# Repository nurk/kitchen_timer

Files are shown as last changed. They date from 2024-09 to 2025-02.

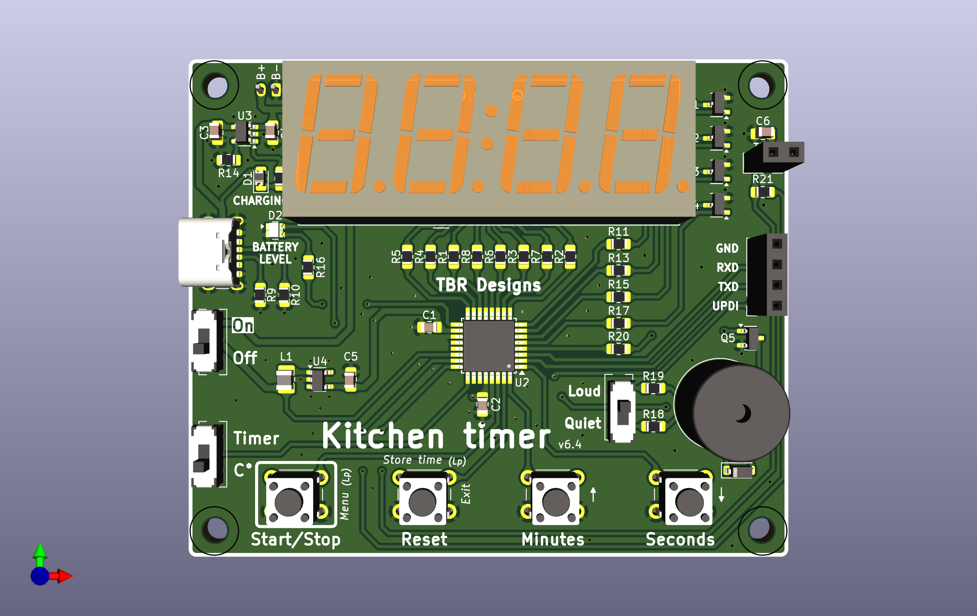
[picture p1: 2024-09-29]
hardware/kitchen_timer_6.4/3D.png

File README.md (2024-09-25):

### *Disclaimer*
*I am not a microcontroller developer nor am I a C-plusplus developer.  I am also definitively not a hardware designer.*

# Kitchen timer

A long time ago my lovely sister gave me a kitchen timer which would beep once when there are 10 minutes left and twice when there are 5 minutes left.  Unfortunately time got the better of the timer and it broke but I got hooked on those features.

I have been unable to find a replacement but after dabbling with some [circuits](https://github.com/nurk/8-bit-cpu) a bit I thought I might be able to make my own.

This repository contains the version(s) that I deem worthy of the internet.

You will find a software and hardware folder with each containing the respective versions.

The hardware folder contains a KiCad project where the symbols and footprints used have been added to a local library.  You will also find a pdf of the [schematic](https://github.com/nurk/kitchen_timer/blob/ce0c0dc44edd9d53a935f777b976885855d0056c/hardware/kitchen_timer_6.3/schematic.pdf), a screenshot of the [pcb](https://github.com/nurk/kitchen_timer/blob/ce0c0dc44edd9d53a935f777b976885855d0056c/hardware/kitchen_timer_6.3/pcb.png) and a screenshot of the [3D rendering](https://github.com/nurk/kitchen_timer/blob/ce0c0dc44edd9d53a935f777b976885855d0056c/hardware/kitchen_timer_6.3/3D.png).

The software folder contains an arduino ide project with the, well, software.

## User guide
I am not going to explain how to use a kitchen timer.  If the main function of the 4 buttons does not speak for themselves I did really bad.  I am only going to explain the extra features.

### Timer / C°
This switch toggles the display to show the timer and the measured temperature.

### Loud / Quiet
I bought cheap buzzers on amazon and they all seem a bit different.  Some are quiet and some are loud.  Because I was tired of changing the inline resistor for the buzzer I added a toggle to switch between two values.  One is louder, the other is quieter.

### Reset long press
Because you can fully turn off this device a way was needed to set the time for when you turn on the device.  The chance of you needing a timer of 0 minutes and 0 seconds is very slim.

After setting a time you can long press the **Reset** button until you hear a second beep and the set time will be stored.  When cycling the power the stored time will be loaded.

### Start/Stop long press
When you long press the **Start/Stop** button the letter `A` will appear and you will have entered the setup menu.  After releasing the **Start/Stop** button you will see `A5. 0`.  Clicking the **Start/Stop** button will cycle through the menu items:  
| Displayed | Meaning |
| :---: | :---: |
| `A5. 0` | 5 minute alarm  |
| `A10.0` | 10 minute alarm |
| `A15.0` | 15 minute alarm |
| `A20.0` | 20 minute alarm |
| `C 0.0` | Temperature offset<sup>*</sup> |

<sup>*</sup> This was added in version 6.4.  It is a `C` because I cannot make a `T` with a 7-segment display.

For the alarms, the value after the `.` is the number of beeps that will sound when there are 'x' minutes left.  You can use the **Minutes** button to increase the number of beeps and the **Seconds** button to decrease the number of beeps.

To exit the setup menu just click the **Reset** button.

## Miscellaneous
Some component sizes might seem big for some.  Especially resistors and capacitors of size 0805.  Keep in mind I am hand soldering this and I am becoming an old fart with bad eyesight.

The microcontroller is an ATmega4808 which has way more flash storage than is needed.  I still chose this one because it is what I have and I am not going to buy a new variant for each project I do.

The battery charge controller I chose only charges at 500mA.  So you will need a battery with at least this capacity (or you have to change the resistor on the programming pin).  I have a 2000mA battery connected and I takes a fair while to charge.

**This is not a cost effective way to get a kitchen timer.  If you need one you are better of going to the store and buying one.**

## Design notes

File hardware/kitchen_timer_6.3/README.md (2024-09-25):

The battery indicator does not work on this version.

I connected the battery voltage to PIN_PF0 but that pin cannot do `analogRead`.

Version 6.4 fixes this issue.

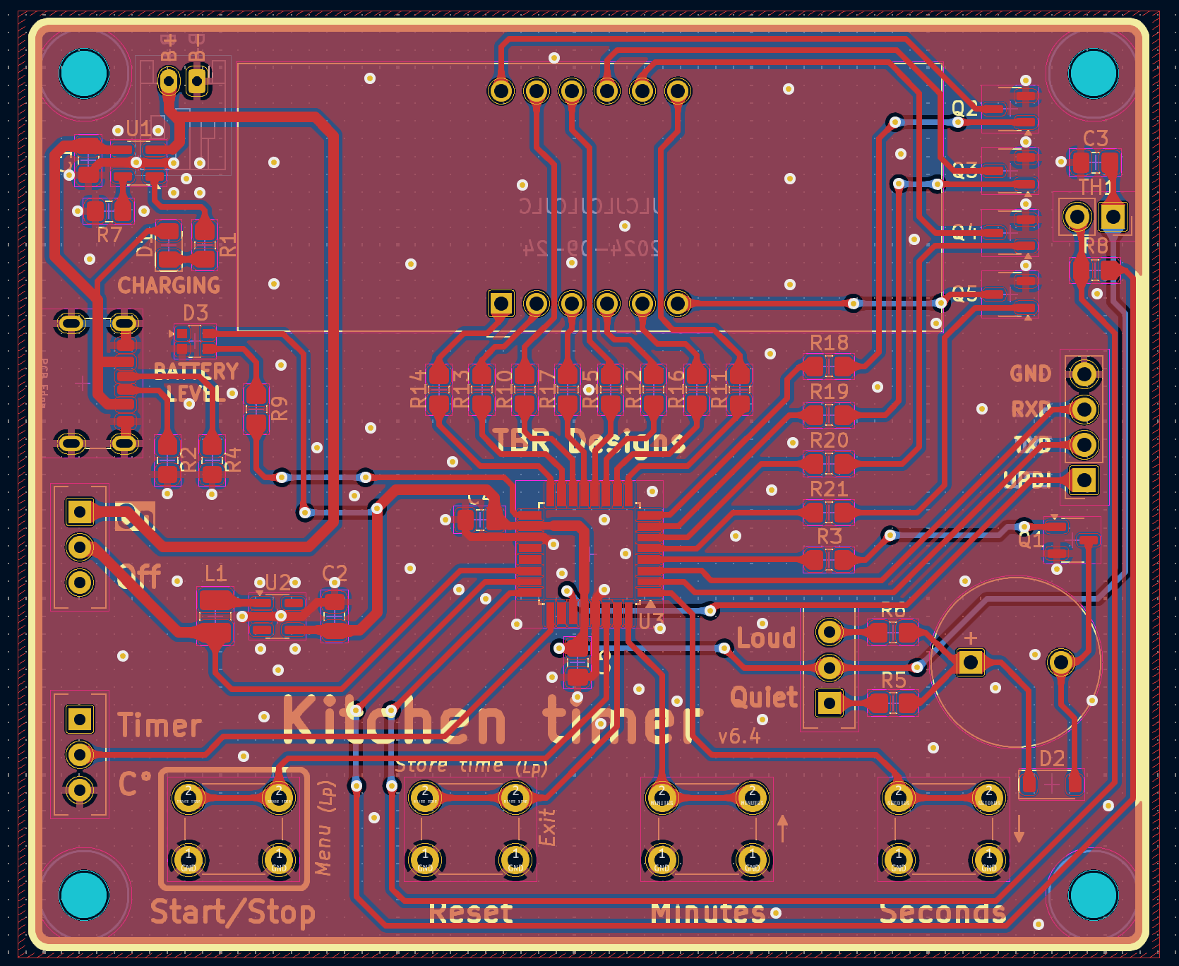
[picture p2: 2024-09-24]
hardware/kitchen_timer_6.4/pcb.png

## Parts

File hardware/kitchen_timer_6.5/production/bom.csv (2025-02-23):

Designator | Footprint | Quantity | Value | LCSC Part #
BZ1 | MagneticBuzzer_ProSignal_ABT-410-RC | 1 | Buzzer
C1, C2, C6 | 0805 | 3 | 100n
C3 | 0805 | 1 | 10u
C4, C5 | 0805 | 2 | 22u
D1 | 0805 | 1 | CHRG_LED
D2 | LED_WS2812B-2020_2.0x2.0mm | 1 | WS2812B-2020
D3 | D_SOD-123 | 1 | MBR0520
J1 | JST_PH_S2B-PH-K_1x02_P2.00mm_Horizontal | 1 | JST PH 2.0
J2 | USB_C_Receptacle_GCT_USB4125-xx-x-0190_6P_TopMnt_Horizontal | 1 | USB_C
J3 | PinSocket_1x04_P2.54mm_Vertical | 1 | BREAKOUT
L1 | 1008 | 1 | CVH252009-2R2M
Q1, Q2, Q3, Q4, Q5 | SOT-23-3 | 5 | MMBT2222A
R1, R2, R3, R4, R5, R6, R7, R8 | 0805 | 8 | 220R
R10, R9 | 0805 | 2 | 5k1 1%
R11, R12, R13, R15, R17, R20 | 0805 | 6 | 1k
R14 | 0805 | 1 | 2k 1%
R16 | 0805 | 1 | 300R
R18 | 0805 | 1 | 47R
R19 | 0805 | 1 | 5R
R21 | 0805 | 1 | 10k 1%
SW1 | SW_Slide_SPDT_MINI | 1 | ON/OFF
SW2 | SW_PUSH_6mm | 1 | SECONDS
SW3 | SW_PUSH_6mm | 1 | MINUTES
SW4 | SW_PUSH_6mm | 1 | RESET_TIME
SW5 | SW_Slide_SPDT_MINI | 1 | VOLUME
SW6 | SW_PUSH_6mm | 1 | START/STOP
SW7 | SW_Slide_SPDT_MINI | 1 | FUNCTION_SELECTOR
TH1 | PinSocket_1x02_P2.54mm_Vertical | 1 | NRBE104F3435B2F
U1 | CA56-12EWA | 1 | LTC-5723HR
U2 | TQFP-32_7x7mm_P0.8mm | 1 | ATmega4808-A
U3 | SOT-23-5 | 1 | DIO5518B
U4 | SOT-23-5 | 1 | TPS613222ADBV
U5 | SOT-23-5 | 1 | LM321

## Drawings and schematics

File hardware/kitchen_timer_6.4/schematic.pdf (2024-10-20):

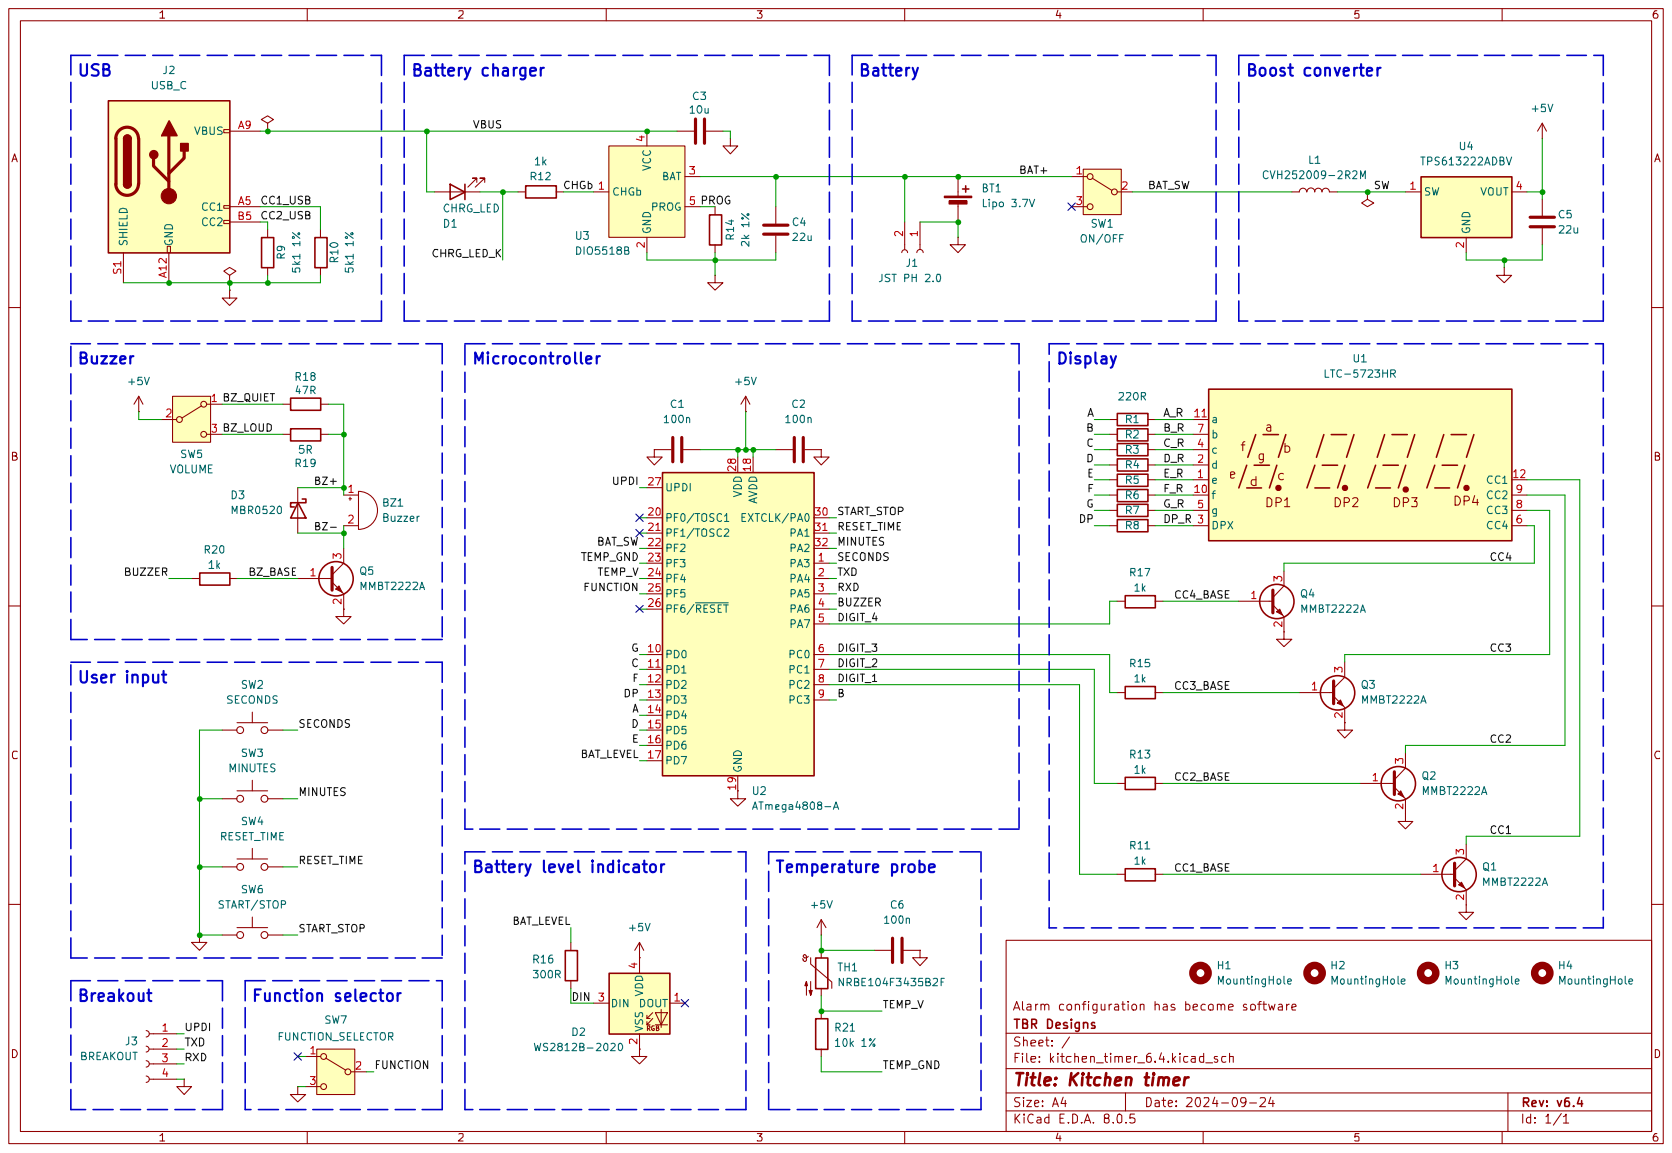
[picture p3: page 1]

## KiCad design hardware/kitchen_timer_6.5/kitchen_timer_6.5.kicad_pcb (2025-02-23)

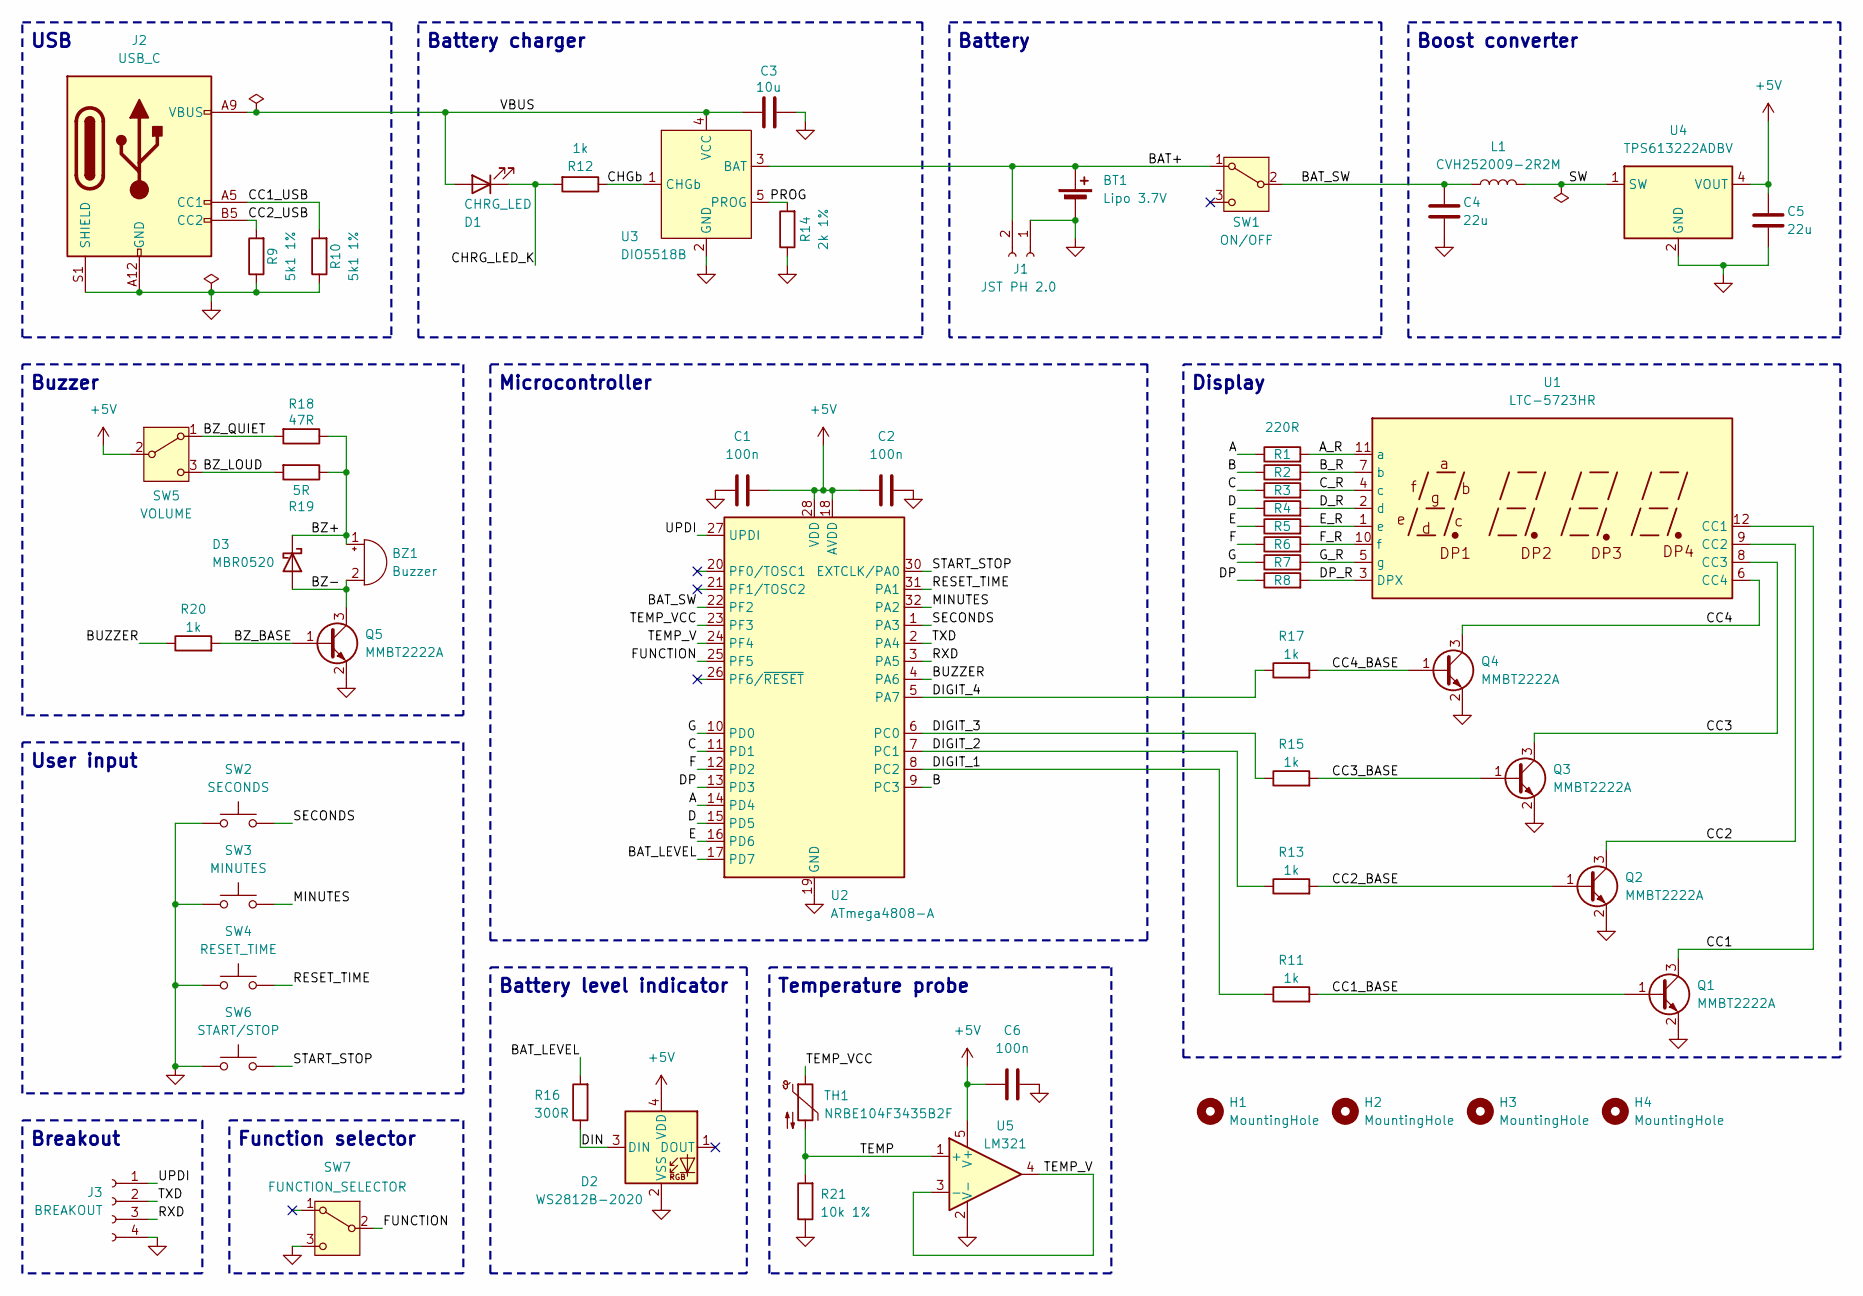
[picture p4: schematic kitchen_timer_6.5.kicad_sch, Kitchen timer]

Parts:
BT1: Lipo 3.7V
BZ1: Buzzer; MagneticBuzzer_ProSignal_ABT-410-RC
C1, C2, C6: 100n; C_0805_2012Metric_Pad1.18x1.45mm_HandSolder
C3: 10u; C_0805_2012Metric_Pad1.18x1.45mm_HandSolder
C4, C5: 22u; C_0805_2012Metric_Pad1.18x1.45mm_HandSolder
D1: CHRG_LED; D_0805_2012Metric_Pad1.15x1.40mm_HandSolder
D2: WS2812B-2020; LED_WS2812B-2020_2.0x2.0mm
D3: MBR0520; D_SOD-123
H1, H2, H3, H4: MountingHole; MountingHole_3.2mm_M3
J1: JST PH 2.0; JST_PH_S2B-PH-K_1x02_P2.00mm_Horizontal
J2: USB_C; USB_C_Receptacle_GCT_USB4125-xx-x-0190_6P_TopMnt_Horizontal
J3: BREAKOUT; PinSocket_1x04_P2.54mm_Vertical
L1: CVH252009-2R2M; L_1008_2520Metric_Pad1.43x2.20mm_HandSolder
Q1, Q2, Q3, Q4, Q5: MMBT2222A; SOT-23-3
R1, R2, R3, R4, R5, R6, R7, R8: 220R; R_0805_2012Metric_Pad1.20x1.40mm_HandSolder
R9, R10: 5k1 1%; R_0805_2012Metric_Pad1.20x1.40mm_HandSolder
R11, R12, R13, R15, R17, R20: 1k; R_0805_2012Metric_Pad1.20x1.40mm_HandSolder
R14: 2k 1%; R_0805_2012Metric_Pad1.20x1.40mm_HandSolder
R16: 300R; R_0805_2012Metric_Pad1.20x1.40mm_HandSolder
R18: 47R; R_0805_2012Metric_Pad1.20x1.40mm_HandSolder
R19: 5R; R_0805_2012Metric_Pad1.20x1.40mm_HandSolder
R21: 10k 1%; R_0805_2012Metric_Pad1.20x1.40mm_HandSolder
SW1: ON/OFF; SW_Slide_SPDT_MINI
SW2: SECONDS; SW_PUSH_6mm
SW3: MINUTES; SW_PUSH_6mm
SW4: RESET_TIME; SW_PUSH_6mm
SW5: VOLUME; SW_Slide_SPDT_MINI
SW6: START/STOP; SW_PUSH_6mm
SW7: FUNCTION_SELECTOR; SW_Slide_SPDT_MINI
TH1: NRBE104F3435B2F; PinSocket_1x02_P2.54mm_Vertical
U1: LTC-5723HR; CA56-12EWA
U2: ATmega4808-A; TQFP-32_7x7mm_P0.8mm
U3: DIO5518B; SOT-23-5
U4: TPS613222ADBV; SOT-23-5
U5: LM321; SOT-23-5

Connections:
+5V: C1.1, C2.2, C5.1, C6.2, D2.4 (VDD), SW5.2 (B), U2.18 (AVDD), U2.28 (VDD), U4.4 (VOUT), U5.5 (V+)
/A: R1.1, U2.14 (PD4)
/A_R: R1.2, U1.11 (a)
/B: R2.1, U2.9 (PC3)
/BAT+: BT1.1 (+), J1.2, SW1.1 (A), U3.3 (BAT)
/BAT_LEVEL: R16.2, U2.17 (PD7)
/BAT_SW: C4.1, L1.1, SW1.2 (B), U2.22 (PF2)
/BUZZER: R20.1, U2.4 (PA6)
/BZ+: BZ1.1 (+), D3.1 (K), R18.1, R19.1
/BZ-: BZ1.2 (-), D3.2 (A), Q5.3 (C)
/BZ_BASE: Q5.1 (B), R20.2
/BZ_LOUD: R19.2, SW5.3 (C)
/BZ_QUIET: R18.2, SW5.1 (A)
/B_R: R2.2, U1.7 (b)
/C: R3.1, U2.11 (PD1)
/CC1: Q1.3 (C), U1.12 (CC1)
/CC1_BASE: Q1.1 (B), R11.2
/CC1_USB: J2.A5 (CC1), R10.2
/CC2: Q2.3 (C), U1.9 (CC2)
/CC2_BASE: Q2.1 (B), R13.2
/CC2_USB: J2.B5 (CC2), R9.2
/CC3: Q3.3 (C), U1.8 (CC3)
/CC3_BASE: Q3.1 (B), R15.2
/CC4: Q4.3 (C), U1.6 (CC4)
/CC4_BASE: Q4.1 (B), R17.2
/CHGb: R12.1, U3.1 (CHGb)
/CHRG_LED_K: D1.1 (K), R12.2
/C_R: R3.2, U1.4 (c)
/D: R4.1, U2.15 (PD5)
/DIGIT_1: R11.1, U2.8 (PC2)
/DIGIT_2: R13.1, U2.7 (PC1)
/DIGIT_3: R15.1, U2.6 (PC0)
/DIGIT_4: R17.1, U2.5 (PA7)
/DIN: D2.3 (DIN), R16.1
/DP: R8.1, U2.13 (PD3)
/DP_R: R8.2, U1.3 (DPX)
/D_R: R4.2, U1.2 (d)
/E: R5.1, U2.16 (PD6)
/E_R: R5.2, U1.1 (e)
/F: R6.1, U2.12 (PD2)
/FUNCTION: SW7.2 (B), U2.25 (PF5)
/F_R: R6.2, U1.10 (f)
/G: R7.1, U2.10 (PD0)
/G_R: R7.2, U1.5 (g)
/MINUTES: SW3.2, U2.32 (PA2)
/PROG: R14.2, U3.5 (PROG)
/RESET_TIME: SW4.2, U2.31 (PA1)
/RXD: J3.3, U2.3 (PA5)
/SECONDS: SW2.2, U2.1 (PA3)
/START_STOP: SW6.2, U2.30 (EXTCLK/PA0)
/SW: L1.2, U4.1 (SW)
/TEMP: R21.2, TH1.2, U5.1 (+)
/TEMP_V: U2.24 (PF4), U5.3 (-), U5.4
/TEMP_VCC: TH1.1, U2.23 (PF3)
/TXD: J3.2, U2.2 (PA4)
/UPDI: J3.1, U2.27 (UPDI)
/VBUS: C3.1, D1.2 (A), J2.A9 (VBUS), J2.B9 (VBUS), U3.4 (VCC)
GND: BT1.2 (-), C1.2, C2.1, C3.2, C4.2, C5.2, C6.1, D2.2 (VSS), J1.1, J2.A12 (GND), J2.B12 (GND), J2.S1 (SHIELD), J3.4, Q1.2 (E), Q2.2 (E), Q3.2 (E), Q4.2 (E), Q5.2 (E), R9.1, R10.1, R14.1, R21.1, SW2.1, SW3.1, SW4.1, SW6.1, SW7.3 (C), U2.19 (GND), U2.29 (GND), U3.2 (GND), U4.2 (GND), U5.2 (V-)

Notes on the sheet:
Temperature probe
Battery
Display
Battery level indicator
USB
Function selector
Boost converter
User input
Microcontroller
Buzzer
Breakout
Battery charger

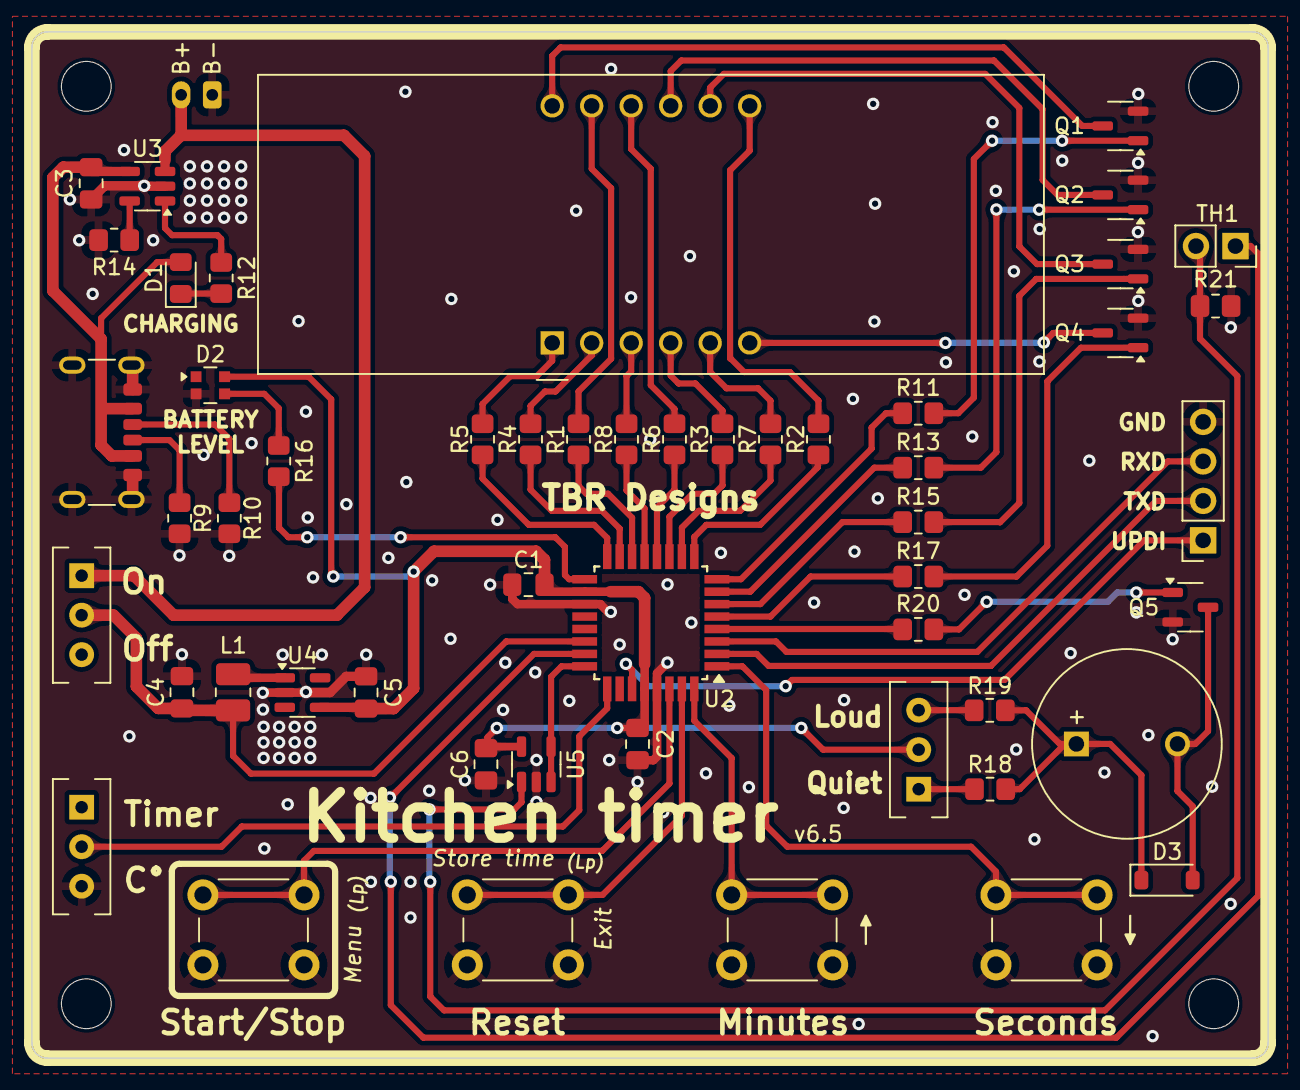
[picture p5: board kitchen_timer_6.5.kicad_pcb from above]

Board: 2 copper layers, 79.5 x 66.0 mm, 57 parts (1 on the bottom side), 58 nets.

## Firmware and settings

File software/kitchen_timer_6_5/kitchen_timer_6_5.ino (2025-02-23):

/**
  SW: 6.4
  HW: 6.4

  ATmega4808
  Internal 16 MHz
  EEPROM retained
  32 pin standard
  Reset pin GPIO
  Serial UPDI
**/

#define DEBUG false
#define Serial \
  if (DEBUG) Serial

#include "HystFilter.h"
#include <JC_Button.h>
#include <EEPROM.h>
#include <Adafruit_NeoPixel.h>

#define USE_TIMER_0 true
#define TIMER_INTERVAL_MS 1000L
#include <megaAVR_TimerInterrupt.h>

#define A_SEGMENT PIN_PD4
#define B_SEGMENT PIN_PC3
#define C_SEGMENT PIN_PD1
#define D_SEGMENT PIN_PD5
#define E_SEGMENT PIN_PD6
#define F_SEGMENT PIN_PD2
#define G_SEGMENT PIN_PD0
#define DP_SEGMENT PIN_PD3

#define DIGIT_1 PIN_PC2
#define DIGIT_2 PIN_PC1
#define DIGIT_3 PIN_PC0
#define DIGIT_4 PIN_PA7

#define START_STOP PIN_PA0
#define TIME_RESET PIN_PA1
#define MINUTES PIN_PA2
#define SECONDS PIN_PA3

#define BUZZER PIN_PA6

#define BATTERY_LEVEL_PIN PIN_PF2
#define BATTERY_LEVEL_LED_PIN PIN_PD7

#define TEMP_V PIN_PF4
#define TEMP_VCC PIN_PF3
#define FUNCTION PIN_PF5

const int segments[] = { A_SEGMENT, B_SEGMENT, C_SEGMENT, D_SEGMENT, E_SEGMENT, F_SEGMENT, G_SEGMENT, DP_SEGMENT };
const int digits[] = { DIGIT_1, DIGIT_2, DIGIT_3, DIGIT_4 };

// Dp G F E D C B A
const byte numbers[] = {
  0X3F,  // 0
  0X06,  // 1
  0X5B,  // 2
  0X4F,  // 3
  0X66,  // 4
  0X6D,  // 5
  0X7C,  // 6
  0X07,  // 7
  0X7F,  // 8
  0X6F   // 9
};
const byte blankDigit = 0X00;
const byte aDigit = 0X77;
const byte cDigit = 0X39;
const byte minusDigit = 0X40;

int currentDigit = 0;
unsigned long digitMillis = millis();

const Button startStopButton(START_STOP);
const Button timeResetButton(TIME_RESET);
const Button minutesButton(MINUTES);
const Button secondsButton(SECONDS);
boolean resetLongPressed = false;
// for state machine used by mintues and seconds button
// see https://github.com/JChristensen/JC_Button/blob/master/examples/UpDown/UpDown.ino
const unsigned long REPEAT_FIRST(500);
const unsigned long REPEAT_INCR(100);
unsigned long rpt(REPEAT_FIRST);
enum states_t { WAIT,
                MINUTES_UP,
                SECONDS_UP };
states_t STATE;

int seconds = 0;
int minutes = 0;
int previousSeconds = 0;
int previousMinutes = 0;
const int minutesAddress = 0;
const int secondsAddress = 2;
bool counting = false;
bool buzzing = false;
bool pauzed = false;

const int beepTone = 1800;

int bleepsToDo = 0;
unsigned long nextBleepTime = millis();

int bleepBlocksToDo = 0;
unsigned long nextBleepBlockTime = millis();

boolean setupMenu = false;
int menuItem = 0;
int alarm5MinutesBleeps = 0;
int alarm10MinutesBleeps = 0;
int alarm15MinutesBleeps = 0;
int alarm20MinutesBleeps = 0;
const int alarm5MinutesAddress = 4;
const int alarm10MinutesAddress = 6;
const int alarm15MinutesAddress = 8;
const int alarm20MinutesAddress = 10;

Adafruit_NeoPixel pixels(1, BATTERY_LEVEL_LED_PIN, NEO_GRB + NEO_KHZ800);
unsigned long nextBatteryLevelCheck = 0;

unsigned long nextFunctionCheck = millis();
boolean isTimerDisplayed = true;

unsigned long nextTemperatureCheck = millis();
int tempMostSignificant = 0;
int tempLeastSignificant = 0;
float tempOffset = 0.0;
const int tempOffsetAddress = 12;  // 4 bytes

void setup() {
  Serial.swap(1);
  Serial.begin(9600);
  pinMode(A_SEGMENT, OUTPUT);
  pinMode(B_SEGMENT, OUTPUT);
  pinMode(C_SEGMENT, OUTPUT);
  pinMode(D_SEGMENT, OUTPUT);
  pinMode(E_SEGMENT, OUTPUT);
  pinMode(F_SEGMENT, OUTPUT);
  pinMode(G_SEGMENT, OUTPUT);
  pinMode(DP_SEGMENT, OUTPUT);

  pinMode(DIGIT_1, OUTPUT);
  pinMode(DIGIT_2, OUTPUT);
  pinMode(DIGIT_3, OUTPUT);
  pinMode(DIGIT_4, OUTPUT);

  pinMode(BUZZER, OUTPUT);

  pinMode(FUNCTION, INPUT_PULLUP);
  pinMode(TEMP_VCC, OUTPUT);

  isTimerDisplayed = digitalRead(FUNCTION) == HIGH;

  startStopButton.begin();
  timeResetButton.begin();
  minutesButton.begin();
  secondsButton.begin();

  ITimer0.init();
  ITimer0.attachInterruptInterval(TIMER_INTERVAL_MS, timerHandler);

  loadEEPROM();

  pixels.begin();
  pixels.setBrightness(10);
  pixels.setPixelColor(0, pixels.Color(255, 255, 255));
  pixels.show();

  digitalWrite(TEMP_VCC, HIGH);
  convertThermistorReading(analogRead(TEMP_V));
  digitalWrite(TEMP_VCC, LOW);
}

void loop() {
  handleFunction();
  handleBatteryLevel();
  handleTemperature();
  multiplexDigits();
  handleButtons();
  handleBleeps();
}

void loadEEPROM() {
  EEPROM.get(secondsAddress, seconds);
  EEPROM.get(minutesAddress, minutes);
  EEPROM.get(alarm5MinutesAddress, alarm5MinutesBleeps);
  EEPROM.get(alarm10MinutesAddress, alarm10MinutesBleeps);
  EEPROM.get(alarm15MinutesAddress, alarm15MinutesBleeps);
  EEPROM.get(alarm20MinutesAddress, alarm20MinutesBleeps);
  EEPROM.get(tempOffsetAddress, tempOffset);

  seconds = min(59, max(0, seconds));
  minutes = min(99, max(0, minutes));
  previousSeconds = seconds;
  previousMinutes = minutes;

  alarm5MinutesBleeps = min(9, max(0, alarm5MinutesBleeps));
  alarm10MinutesBleeps = min(9, max(0, alarm10MinutesBleeps));
  alarm15MinutesBleeps = min(9, max(0, alarm15MinutesBleeps));
  alarm20MinutesBleeps = min(9, max(0, alarm20MinutesBleeps));

  tempOffset = fmin(9.9, fmax(-9.9, tempOffset));
}

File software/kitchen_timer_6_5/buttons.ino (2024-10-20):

void handleButtons() {
  startStopButton.read();
  timeResetButton.read();
  minutesButton.read();
  secondsButton.read();

  handleStarStopButton();
  handleTimeResetButton();
  handleTimeButtons();
}

void handleStarStopButton() {
  if (startStopButton.wasPressed()) {
    buttonTone();
  }
  if (startStopButton.pressedFor(1000)) {
    setupMenu = true;
    menuItem = -1;
  }
  if (startStopButton.wasReleased()) {
    if (setupMenu) {
      menuItem = (menuItem + 1) % 5;
    } else {
      if (buzzing) {
        resetBuzzing();
      } else {
        if (pauzed && counting) {
          pauzed = false;
        } else {
          if (counting) {
            pauzed = true;
          } else if (!(minutes == 0 && seconds == 0)) {
            counting = true;
            pauzed = false;
          }
        }
      }
    }
  }
}

void resetBuzzing() {
  stopBleeps();
  counting = false;
  minutes = previousMinutes;
  seconds = previousSeconds;
}

void handleTimeResetButton() {
  if (timeResetButton.wasPressed()) {
    buttonTone();
  }
  if (timeResetButton.pressedFor(1000)) {
    if (!resetLongPressed) {
      buttonTone();
    }
    resetLongPressed = true;
  }
  if (timeResetButton.wasReleased()) {
    if (resetLongPressed) {
      EEPROM.put(minutesAddress, previousMinutes);
      EEPROM.put(secondsAddress, previousSeconds);
    } else if (setupMenu) {
      setupMenu = false;
    } else {
      counting = false;
      pauzed = false;
      stopBleeps();
      minutes = 0;
      seconds = 0;
      previousSeconds = seconds;
      previousMinutes = minutes;
    }
    resetLongPressed = false;
  }
}

void handleTimeButtons() {
  switch (STATE) {
    case WAIT:
      if (minutesButton.wasPressed()) {
        STATE = MINUTES_UP;
      } else if (minutesButton.wasReleased()) {
        rpt = REPEAT_FIRST;
      } else if (minutesButton.pressedFor(rpt)) {
        rpt += REPEAT_INCR;
        STATE = MINUTES_UP;
      } else if (secondsButton.wasPressed()) {
        STATE = SECONDS_UP;
      } else if (secondsButton.wasReleased()) {
        rpt = REPEAT_FIRST;
      } else if (secondsButton.pressedFor(rpt)) {
        rpt += REPEAT_INCR;
        STATE = SECONDS_UP;
      }
      break;
    case MINUTES_UP:
      buttonTone();
      if (setupMenu) {
        menuUp();
      } else {
        minutes++;
        if (minutes > 99) {
          minutes = 0;
        }
        previousMinutes = minutes;
      }
      STATE = WAIT;
      break;
    case SECONDS_UP:
      buttonTone();
      if (setupMenu) {
        menuDown();
      } else {
        seconds++;
        if (seconds > 59) {
          seconds = 0;
        }
        previousSeconds = seconds;
      }
      STATE = WAIT;
      break;
  }
}

void menuUp() {
  switch (menuItem) {
    case 0:
      alarm5MinutesBleeps = min(9, alarm5MinutesBleeps + 1);
      EEPROM.put(alarm5MinutesAddress, alarm5MinutesBleeps);
      break;
    case 1:
      alarm10MinutesBleeps = min(9, alarm10MinutesBleeps + 1);
      EEPROM.put(alarm10MinutesAddress, alarm10MinutesBleeps);
      break;
    case 2:
      alarm15MinutesBleeps = min(9, alarm15MinutesBleeps + 1);
      EEPROM.put(alarm15MinutesAddress, alarm15MinutesBleeps);
      break;
    case 3:
      alarm20MinutesBleeps = min(9, alarm20MinutesBleeps + 1);
      EEPROM.put(alarm20MinutesAddress, alarm20MinutesBleeps);
      break;
    case 4:
      tempOffset = fmin(9.9, tempOffset + 0.1);
      EEPROM.put(tempOffsetAddress, tempOffset);
      break;
  }
}

void menuDown() {
  switch (menuItem) {
    case 0:
      alarm5MinutesBleeps = max(0, alarm5MinutesBleeps - 1);
      EEPROM.put(alarm5MinutesAddress, alarm5MinutesBleeps);
      break;
    case 1:
      alarm10MinutesBleeps = max(0, alarm10MinutesBleeps - 1);
      EEPROM.put(alarm10MinutesAddress, alarm10MinutesBleeps);
      break;
    case 2:
      alarm15MinutesBleeps = max(0, alarm15MinutesBleeps - 1);
      EEPROM.put(alarm15MinutesAddress, alarm15MinutesBleeps);
      break;
    case 3:
      alarm20MinutesBleeps = max(0, alarm20MinutesBleeps - 1);
      EEPROM.put(alarm20MinutesAddress, alarm20MinutesBleeps);
      break;
    case 4:
      tempOffset = fmax(-9.9, tempOffset - 0.1);
      EEPROM.put(tempOffsetAddress, tempOffset);
      break;
  }
}

void buttonTone() {
  digitalWrite(BUZZER, LOW);
  tone(BUZZER, beepTone, 60);
}

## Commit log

2024-09-05 add schematic
2024-09-05 update git ignore
    [bom.csv, designators.csv, positions.csv]
2024-09-07 change to battery percentage
2024-09-07 add hysteresis for battery level
2024-09-24 version 6.4. PF0 cannot do analog read
    [bom.csv, designators.csv, kitchen_timer_6.4.kicad_pcb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]
2024-09-24 updated pcb.png
2024-09-24 new production file
    [kitchen_timer_6.4.kicad_pcb]
2024-09-25 add temperature offset menu item
2024-09-29 extra capacitor
    [bom.csv, designators.csv, kitchen_timer_6.4.kicad_pcb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]
2024-10-04 actually order production files
    [kitchen_timer_6.4.kicad_pcb]
2024-10-20 redid the schematic without reannotating. Hoping to me the usb -> battery charger -> boost converter more clear
    [kitchen_timer_6.4.kicad_pcb, kitchen_timer_6.4.kicad_sch]
2025-02-23 added opamp for temp sensing
    [bom.csv, designators.csv, kitchen_timer_6.5.kicad_pcb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]
2025-02-23 converted temp_gnd to temp_vcc and change temperature reading logic
    [kitchen_timer_6.5.kicad_pcb, kitchen_timer_6.5.kicad_sch]
